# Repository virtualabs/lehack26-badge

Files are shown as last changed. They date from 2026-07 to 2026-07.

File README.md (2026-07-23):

leHACK 2026 Collector Badge
===========================

This project is a small collector badge designed for [leHACK 2026](https://lehack.org) rewarding
those who managed to hack my electronic hat during the event. Since this badge looks nice and required
a few weeks of effort to be designed and assembled, I thought it could be worth it to share the design
files and its original firmware (which was a bit late, actually, and had been finished a few weeks after
the event took place...).

* [design](./design) contains my FreeCAD project file as well as the corresponding STL files
* [electronics](./electronics) contains the final export (Gerber files for JLCPCB) and the schematics. BOM is still missing but should be added pretty soon.
* [firmware](./firmware) contains the source code of the firmware, which relies on a [specific version of TFT_eSPI](https://medium.com/@androidcrypto/getting-started-with-an-esp32-c6-waveshare-lcd-device-with-1-47-inch-st7789-tft-display-07804fdc589a), the settings used are provided in this directory

Design process
--------------

This badge has been designed to use a 1200 mAh 103040 Li-ion battery to keep it alive during at least a full day.
Its assembly requires 4 M3 6mm self-taping screws to lock the two main halves of its shell in place. Two button
caps have been designed in the shell itself, relying on the flexibility of the filament used to print these parts.

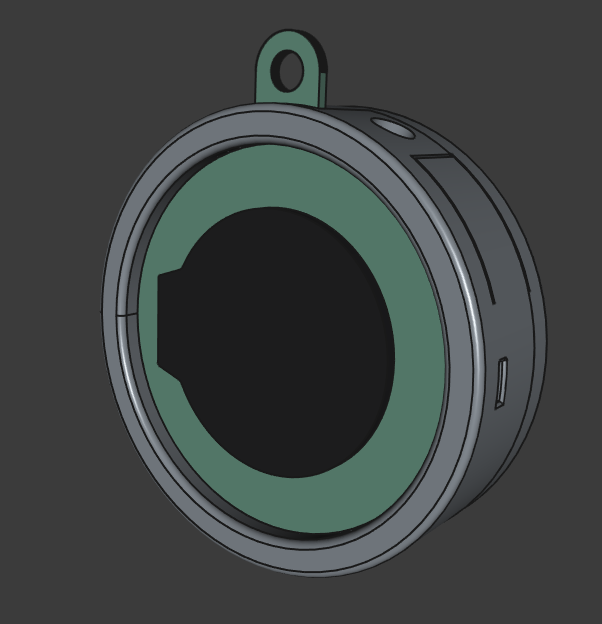
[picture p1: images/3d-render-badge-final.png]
Final assembly, as seen in FreeCAD

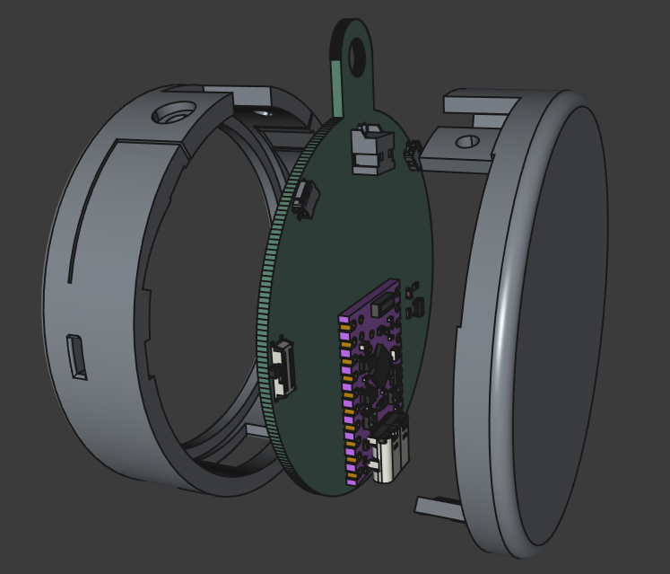
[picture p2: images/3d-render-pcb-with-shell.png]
Exploded assembly, as seen in FreeCAD

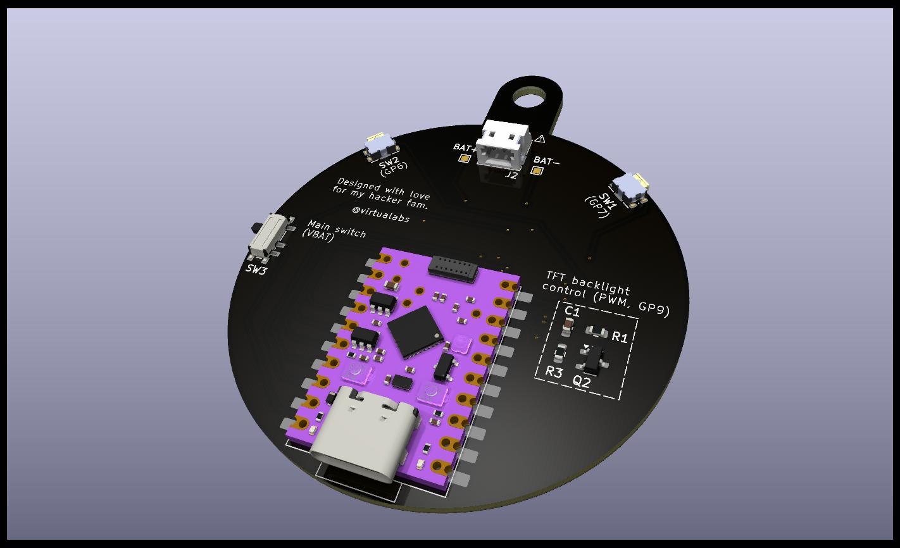
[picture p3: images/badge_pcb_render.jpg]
Main PCB


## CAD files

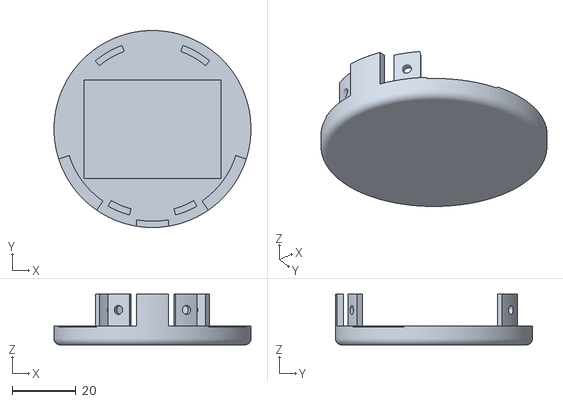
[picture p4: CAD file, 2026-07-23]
design/bottom-shell.stl
62.0 x 62.0 x 16.0

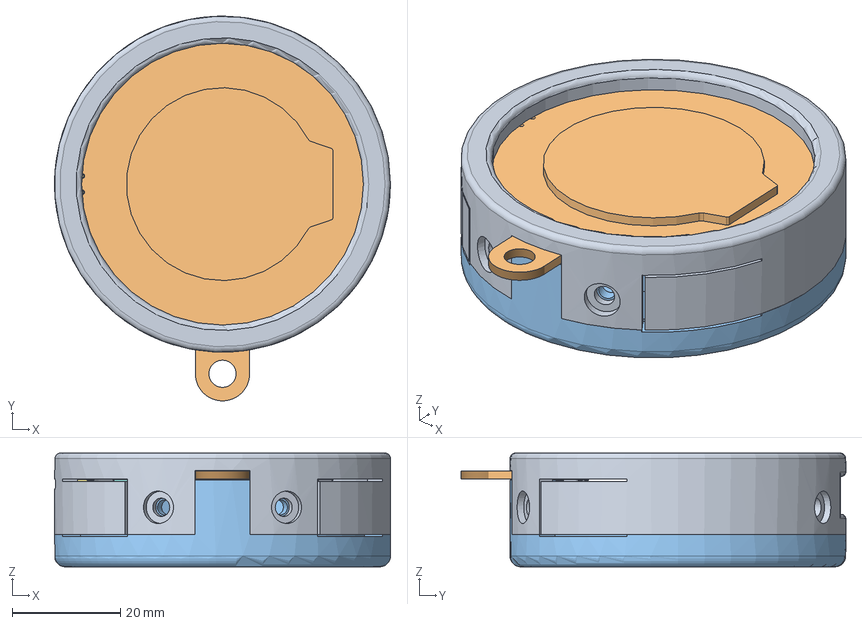
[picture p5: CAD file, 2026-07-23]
design/BadgeCollector.FCStd
62.0 x 71.0 x 21.0 mm
BoitierInferieur
round-display001
SOT-024
C_0603_1608Metric001
R_0603_1608Metric002
R_0603_1608Metric003
SW_SPDT_PCM013
KMS2x3GPxxx
SxB-ZR-SM4A White_2
PCB001
USB_C_Receptacle_16P_TopMnt_Horizontal_GCT_USB4105-xx-A037
USB_C_Receptacle_16P_TopMnt_Horizontal_GCT_USB4105-xx-A038
USB_C_Receptacle_16P_TopMnt_Horizontal_GCT_USB4105-xx-A039
USB_C_Receptacle_16P_TopMnt_Horizontal_GCT_USB4105-xx-A040
USB_C_Receptacle_16P_TopMnt_Horizontal_GCT_USB4105-xx-A041
USB_C_Receptacle_16P_TopMnt_Horizontal_GCT_USB4105-xx-A042
USB_C_Receptacle_16P_TopMnt_Horizontal_GCT_USB4105-xx-A043
USB_C_Receptacle_16P_TopMnt_Horizontal_GCT_USB4105-xx-A044
USB_C_Receptacle_16P_TopMnt_Horizontal_GCT_USB4105-xx-A045
USB_C_Receptacle_16P_TopMnt_Horizontal_GCT_USB4105-xx-A046
USB_C_Receptacle_16P_TopMnt_Horizontal_GCT_USB4105-xx-A047
USB_C_Receptacle_16P_TopMnt_Horizontal_GCT_USB4105-xx-A048
USB_C_Receptacle_16P_TopMnt_Horizontal_GCT_USB4105-xx-A049
USB_C_Receptacle_16P_TopMnt_Horizontal_GCT_USB4105-xx-A050
USB_C_Receptacle_16P_TopMnt_Horizontal_GCT_USB4105-xx-A051
USB_C_Receptacle_16P_TopMnt_Horizontal_GCT_USB4105-xx-A052
USB_C_Receptacle_16P_TopMnt_Horizontal_GCT_USB4105-xx-A053
USB_C_Receptacle_16P_TopMnt_Horizontal_GCT_USB4105-xx-A054
USB_C_Receptacle_16P_TopMnt_Horizontal_GCT_USB4105-xx-A055
USB_C_Receptacle_16P_TopMnt_Horizontal_GCT_USB4105-xx-A056
USB_C_Receptacle_16P_TopMnt_Horizontal_GCT_USB4105-xx-A057
USB_C_Receptacle_16P_TopMnt_Horizontal_GCT_USB4105-xx-A058
USB_C_Receptacle_16P_TopMnt_Horizontal_GCT_USB4105-xx-A059
USB_C_Receptacle_16P_TopMnt_Horizontal_GCT_USB4105-xx-A060
USB_C_Receptacle_16P_TopMnt_Horizontal_GCT_USB4105-xx-A061
USB_C_Receptacle_16P_TopMnt_Horizontal_GCT_USB4105-xx-A062
USB_C_Receptacle_16P_TopMnt_Horizontal_GCT_USB4105-xx-A063
USB_C_Receptacle_16P_TopMnt_Horizontal_GCT_USB4105-xx-A064
USB_C_Receptacle_16P_TopMnt_Horizontal_GCT_USB4105-xx-A065
USB_C_Receptacle_16P_TopMnt_Horizontal_GCT_USB4105-xx-A066
USB_C_Receptacle_16P_TopMnt_Horizontal_GCT_USB4105-xx-A067
USB_C_Receptacle_16P_TopMnt_Horizontal_GCT_USB4105-xx-A068
USB_C_Receptacle_16P_TopMnt_Horizontal_GCT_USB4105-xx-A069
USB_C_Receptacle_16P_TopMnt_Horizontal_GCT_USB4105-xx-A070
USB_C_Receptacle_16P_TopMnt_Horizontal_GCT_USB4105-xx-A071
USB_C_Receptacle_16P_TopMnt_Horizontal_GCT_USB4105-xx-A072
Button_black_002
Button_black_003
io23
io21
io22
io12
io13
Corps
Corps001
Corps002
Corps003
Corps004
Corps005
Corps006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

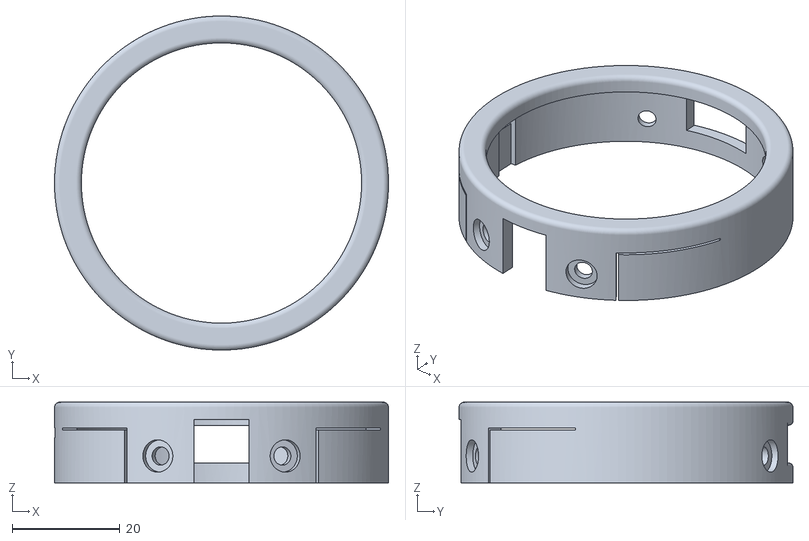
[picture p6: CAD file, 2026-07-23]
design/top-shell.stl
62.0 x 62.0 x 15.0

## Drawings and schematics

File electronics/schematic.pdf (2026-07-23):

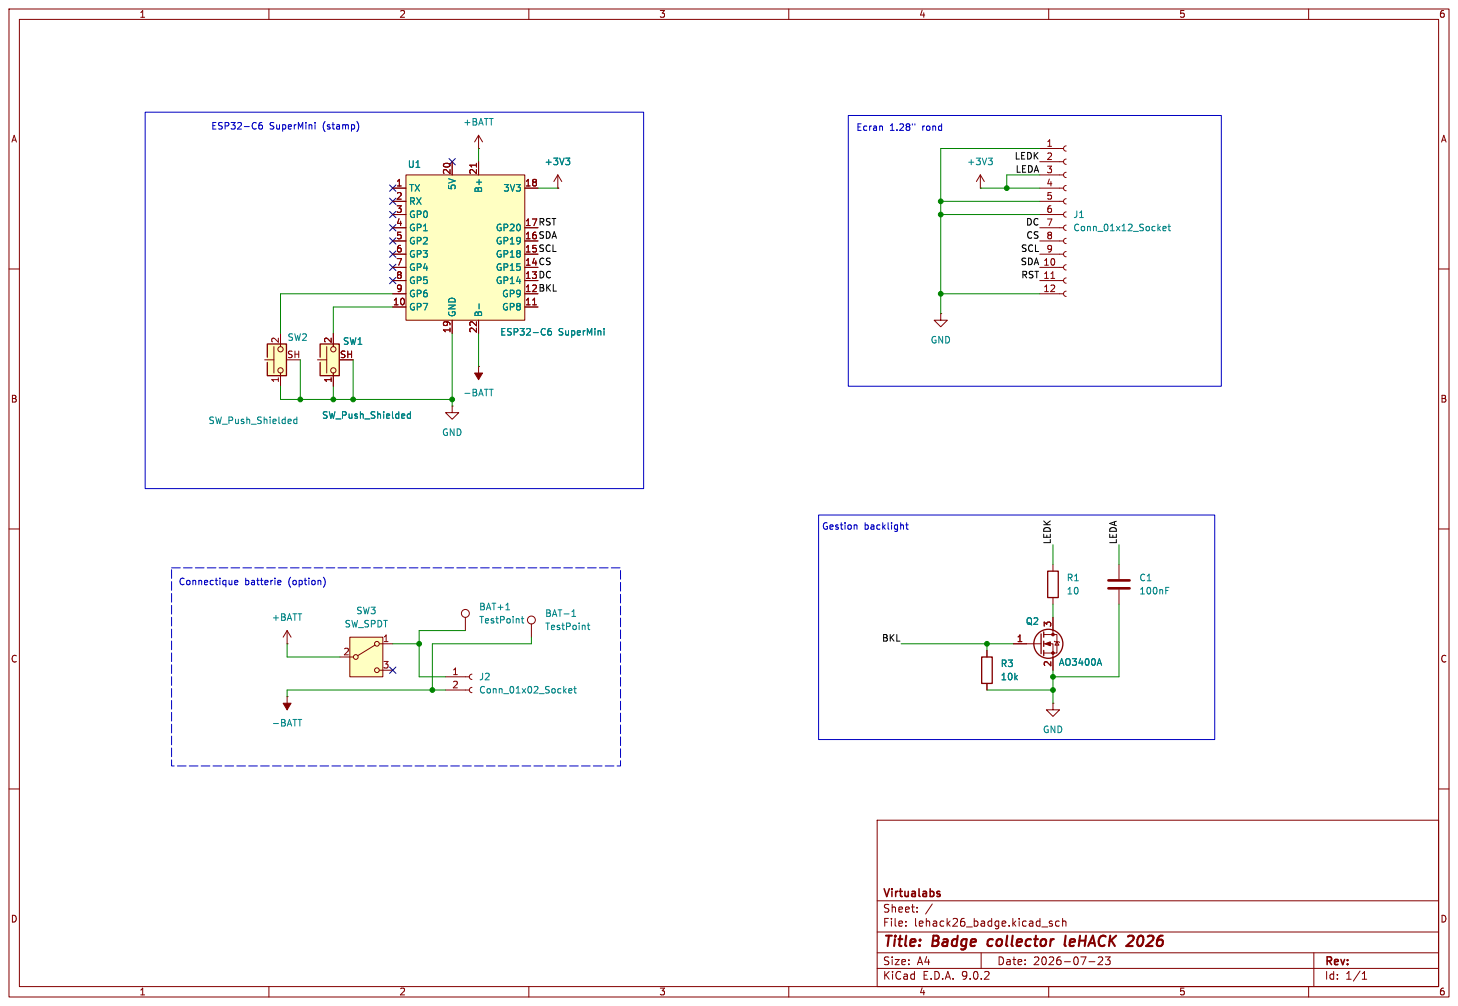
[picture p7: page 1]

Id: 1/1 Title: Badge collector leHACK 2026

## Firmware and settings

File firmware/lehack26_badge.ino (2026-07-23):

#include <SPI.h>
#include <TFT_eSPI.h>
#include "face.hpp"
#include "animator.hpp"
#include "scanner.hpp"
#include "settings.hpp"

#define TFT_MOSI 19
#define TFT_SCLK 18
#define TFT_RST 20 // The ESP32 pin GPIO27 connected to the RST pin of the circular TFT display
#define TFT_DC 14 // The ESP32 pin GPIO25 connected to the DC pin of the circular TFT display
#define TFT_CS 15 

// Defines default eyes position
#define EYE_SPACING   20
#define EYE_SIZE      15
#define LEYE_X        ((240 - 2*EYE_SIZE - EYE_SPACING)/2)
#define REYE_X        (LEYE_X + EYE_SIZE + EYE_SPACING)
#define EYE_Y         (60)

#define SCREEN_FPS    24
#define REFRESH_DELAY 17

#define SW_LEFT       7
#define SW_RIGHT      6         

#define MOOD_COOLDOWN 400

uint32_t mark = 0;
uint32_t frames = 0;
int eyes_y = 15, dir=1;
char fps_str[64];

// Paramètre du channel 0 du PWM
const int freq = 5000; // 5000 Hz
const int ledChannel = 0;
const int resolution = 8; // Résolution de 8 bits

volatile int button_pressed = 0;
volatile int idle_delay = 0;
volatile bool happy = true;
volatile int mood_cooldown = MOOD_COOLDOWN;

// Create an handle for the queue
QueueHandle_t moodQueue = NULL;

char device_report[24];

TFT_eSPI tft = TFT_eSPI();
PalFace face = PalFace(TFT_SKYBLUE);
Animator animator(face);
Settings settings = Settings();

TFT_eSprite buffer = TFT_eSprite(&tft);

// Interrupt Service Routine (ISR)
void ARDUINO_ISR_ATTR button_handler() {
  if (digitalRead(SW_LEFT) == 0) {
    button_pressed = 1;
  } else if (digitalRead(SW_RIGHT) == 0) {
    button_pressed = 2;
  } else {
    button_pressed = 0;
  }
}

void update_idle_delay() {
  if (happy) {
    idle_delay = 30 + (esp_random() % 50);
  } else {
    idle_delay = 5 + (esp_random() % 15);
  }
}

void make_angry(void) {
  uint8_t mood = 0;
  xQueueSend(moodQueue, &mood, portMAX_DELAY);

}

void setup() {

  /* Configure backlight. */
  pinMode(9, OUTPUT);
  analogWrite(9, settings.getBacklightLevel());

  /* Buttons. */
  pinMode(SW_LEFT, INPUT_PULLUP);
  pinMode(SW_RIGHT, INPUT_PULLUP);
  attachInterrupt(SW_LEFT, button_handler, FALLING);
  attachInterrupt(SW_RIGHT, button_handler, FALLING);
  
  // put your setup code here, to run once:
  tft.begin();
  tft.setRotation(3);
  tft.fillScreen(BG_COLOR);
  
  tft.setTextColor(TFT_WHITE);
  tft.setTextFont(1);
  tft.setTextSize(2);

  mark = millis();
  frames = 0;

  buffer.createSprite(240, 240);
  face.draw(buffer);
  buffer.pushSprite(0, 0);  

  /* Initialize our mood queue. */
  // Create queue (5 items, each uint16_t)
  moodQueue = xQueueCreate(10, 1);

  scanner_start();

  update_idle_delay();
}

void loop() {
  uint8_t moodNotif = 1;

  // put your main code here, to run repeatedly:
  frames++;
  if ((millis() - mark) > 1) {
    
    /* Decrement idle delay. */
    if (idle_delay > 0)
    {
      idle_delay--;
    }


    /* Handle mood cooldown. */
    if (!happy)
    {
      if (mood_cooldown > 0)
      {
        mood_cooldown--;
      }
      else
      {
        uint8_t mood = 1;
        xQueueSend(moodQueue, &mood, portMAX_DELAY);
      }
    }

    /* display menu OR animated face. */
    if (settings.isMenuVisible())
    {
      settings.draw(buffer);
    }
    else
    {
      animator.animate();
      face.draw(buffer);
    }

    /* Update screen. */
    buffer.pushSprite(0, 0); 

    mark = millis();
  }


  /* Process notifications from queue. */
  if (!animator.hasTransition())
  {
    if (xQueueReceive(moodQueue, &moodNotif, 0) == pdTRUE)
    {
      if (moodNotif == 0) {
        mood_cooldown = MOOD_COOLDOWN;
        happy = false;
        FaceState *start_state = new FaceState(
          animator.getCurrentState().getEyesX(),
          animator.getCurrentState().getEyesY(),
          animator.getCurrentState().getEyesH(),
          animator.getCurrentState().getMouthX(),
          animator.getCurrentState().getMouthY(),
          animator.getCurrentState().getMouthZ()
        );
        FaceState *end_state = new FaceState(120, 120, 25, 120, MOUTH_Y-20, -10);
        Transition *t = new Transition(*start_state, *end_state, 2);
        animator.setTransition(t);
        face.setBgColor(TFT_RED);
        animator.animate();
      } else {
        happy = true;
        FaceState *start_state = new FaceState(
          animator.getCurrentState().getEyesX(),
          animator.getCurrentState().getEyesY(),
          animator.getCurrentState().getEyesH(),
          animator.getCurrentState().getMouthX(),
          animator.getCurrentState().getMouthY(),
          animator.getCurrentState().getMouthZ()
        );
        FaceState *end_state = new FaceState(160, 120, EYE_H, 160, MOUTH_Y, MOUTH_Z);
        Transition *t = new Transition(*start_state, *end_state, 5);
        animator.setTransition(t);
        face.setBgColor(TFT_SKYBLUE);
        animator.animate();
      }
    }
    else if (idle_delay == 0)
    {
      /* Pick a random position for our face. */
      uint32_t x = 80 + (esp_random() % 80);
      uint32_t y = 120 + (esp_random() % 20);
      
      FaceState *start_state = new FaceState(
        animator.getCurrentState().getEyesX(),
        animator.getCurrentState().getEyesY(),
        animator.getCurrentState().getEyesH(),
        animator.getCurrentState().getMouthX(),
        animator.getCurrentState().getMouthY(),
        animator.getCurrentState().getMouthZ()
      );
      FaceState *end_state = new FaceState(x, y, animator.getCurrentState().getEyesH(), x, 40+y, animator.getCurrentState().getMouthZ());
      if (happy) {
        Transition *t = new Transition(*start_state, *end_state, 5 + (esp_random() % 10));
        animator.setTransition(t);
      } else {
        Transition *t = new Transition(*start_state, *end_state, 3 + (esp_random() % 6));
        animator.setTransition(t);
      }
    
      /* Select a new value for idle_delay. */
      update_idle_delay();
    }
  }

  if (button_pressed != 0)
  {
    delay(150);
    settings.onButtonPressed(button_pressed);
    button_pressed = 0; /* Re-arm our button IRQ. */
  }
}
